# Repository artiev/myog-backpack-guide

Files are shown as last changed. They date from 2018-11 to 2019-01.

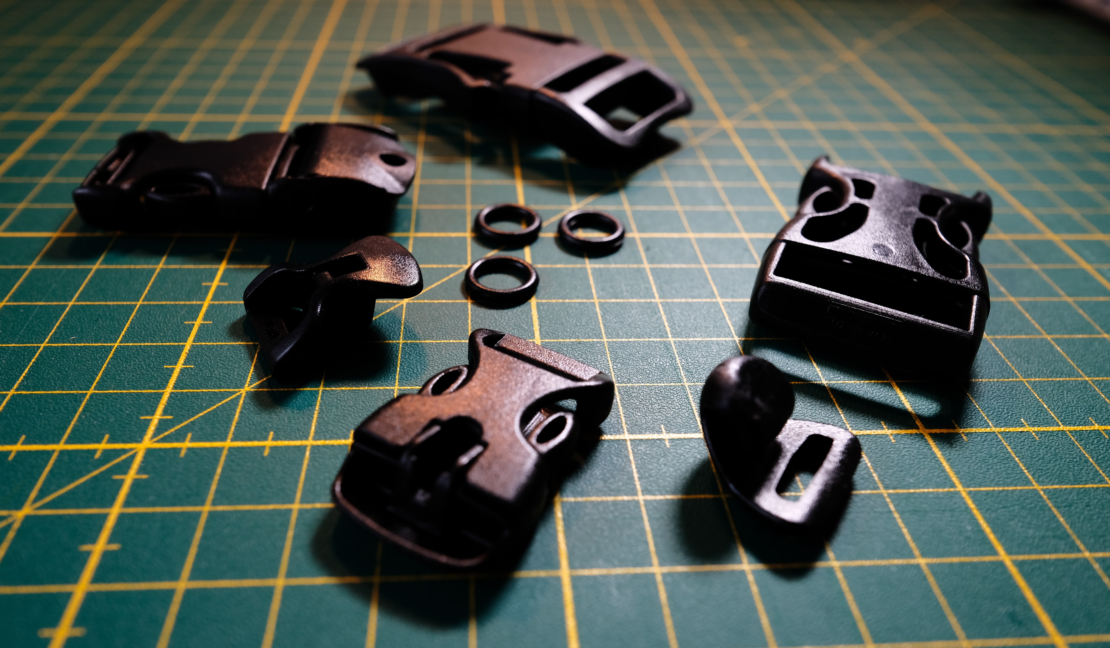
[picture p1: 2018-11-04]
media/images/highres/components-1.jpg

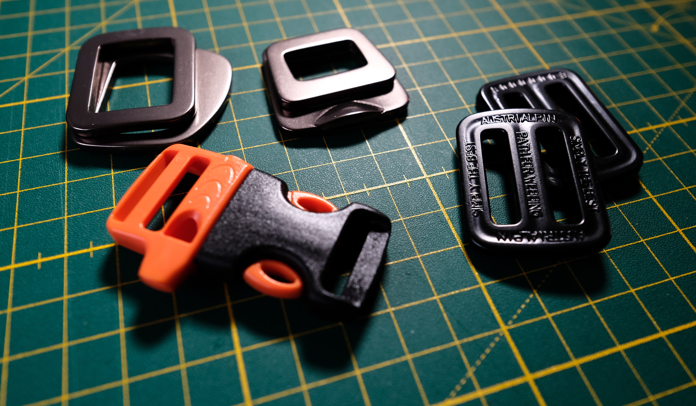
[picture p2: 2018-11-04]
media/images/highres/components-3.jpg

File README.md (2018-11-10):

A guide to building your own backpack
-------------------------------------

There is a growing trend in building outdoor gear: make it lighter.
And there is a will amongst trekkers and hikers alike to focus more on
the essentials than 'hoarding' half of your home on the trail.

This document here presented is a personal take on how I build my lightweight
backpacks. The following picture shows one of my self-made packs.

Example of custom back pack

In this essay, I will go through the complete process I follow to build packs,
and include a number of chapters covering (but not limited to):

- What features I consider when designing a pack.
- Choice of lighter fabrics and which materials I prefer.
- Different building methods and different designs I came up with.
- Complete documentation of a finished pack from design to execution.
- Where I find inspiration.
- How I work on these packs (workspace, tools, etc...)

If you are not familiar with any of this, then have a look
inside. If you are, and you are interested in looking at how I make my
backpacks from the research, sketches and designs to execution and example
photos, then read on!

Feel free to read, share, love, hate, but most of all, comment, review, raise
questions and concerns so I can make it better.

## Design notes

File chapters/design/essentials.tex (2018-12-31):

There is a backpack for any situation, and it's always interesting to look at what others are doing. I have a few backpacks - both commercial and custom made - at home I can analyse inside and out to figure out what I'm interested in. And there is a plethora of detailed pictures and designs on the web, ranging from home made MYOG articles, to high-end ultralight gear manufacturer, to cost-effective mass production design.

\subsection{Features}

When I try to define a set of features for a new backpack, the first step is to define the style and application of my design:

\begin{description}

  \item [Aesthetics] As basic as this sounds, I always enjoy a pack that doesn't look like I put it together in a few minutes. This will cost some extra fabric and or components in most cases, but I prefer it that way.

  \index{padding}
  \item [Load] The padding, weight balance and distribution, boiling down to the basic shape of a backpack is driven by how much weight it will need to carry. This impacts the construction of the shoulder straps, and the of the hip belt as well.

  \item [Weight] The basic weight of the backpack is tied to its construction, the materials used and its shape, the features I build in, etc... I rarely use this as a target, rather, I review everything else and try hard not to over-engineer a pack to limit the extra weight.

  \index{attachment}
  \item [Attachments] There is a ton of options to attach things to a backpack. In outdoor cases, I often have a tent and/or sleeping pad attached on the sides and bottom of the pack, I also use walking poles which I often strap on the side of the pack.

  \index{pocket}
  \item [Pockets] Whether inside or outside, pockets are an essential part of a pack. Depending on how you usually organise your pack, you would consider internal compartments, inside pockets, outside mesh pockets, and so on. I personally don't care much for pockets, as I organise my gear in stuff sacks. But I often need to attach/store things on the outside for easy access, or for drying.

  \index{roll-top}
  \index{velcro}
  \item [Closure] There is a ton of different way to close a backpack. To name but a few, I often consider roll tops, zippers, velcro, tie-ins or a mix of these.

  \index{padding}
  \item [Padding] Padding can be essential, or completely superfluous depending on what you carry, and how you carry it. I always build in a sleeve of some kind following the entire width and length of the pack to be able to add/remove foam padding depending on the trip.

  \index{hip-belt}
  \item [Hip-Belt] For me, and essential part of any hiking/trekking pack. The rare packs I built without a hip-belt, I gave away because I never use them. Now whether I want the hip-belt complete with padding, or just a simple strap depends on the weight I plan on carrying. But it's always a good weight investment.

\end{description}

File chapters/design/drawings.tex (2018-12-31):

When working on a pack, I make tons of sketches and drawings. I start with the basic shape, I add the features I have in mind, I draw multiple mock-ups and variants of that shape, together with its prominent features. Then, I slowly focus on the details, looking at every features, each getting variants of their own. And so on, until I get a pretty good idea of what I want to build.

\index{sketch}
\illustrate{media/images/design-drawings-1}
{Example of drawing process (page one)}
{img:design-drawings-1}

In the sketches from illustration \ref{img:design-drawings-1} and \ref{img:design-drawings-2}, you can see the concept I put together before even starting working on the pack from the picture \ref{img:pack-front-full-intro}. It might not seem like a lot, but it's because I've been sketching similarly built packs for a while, and I used previous sketches, packs and mock-ups as the base for this one. I also put together a collection of images of similar packs and detailed shots of features I was going for, which complement these sketches a lot.

\index{sketch}
\illustrate{media/images/design-drawings-2}
{Example of drawing process (page two)}
{img:design-drawings-2}

\index{feature}
\index{pocket}
\index{shock cord}
\index{compression strap}
\index{hip-belt}
\index{padding}
For me, it's important that I highlight the features I want to add beforehand. For this pack, I knew it would have no external pockets, and instead use a front interlaced elastic shock cord for drying stuff while walking or tucking away some piece of clothing quickly. I also wanted to add a series of straps on each side of the pack for attachment and compression which I could use to strap trekking poles or a water bottle holder. On top of that, I often add a set of attachment on the bottom of the pack which can hold a closed cell foam sleeping pad (important detail, as it tells me the dimensions). In the end, I want to use that pack for loads around 5-7 kg, so a hip belt will be a must, and I might need to have the possibility to add foam padding for my back depending on what I carry.

\illustrate{media/images/pack-front-full}
{The end result of the example design in illustration \ref{img:design-drawings-1}}
{img:pack-front-full-intro}

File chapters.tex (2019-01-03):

\chapter{Introduction} \label{chap:intro}
\input{chapters/introduction/index}

\chapter{My teeny tiny workspace} \label{chap:workspace}
\input{chapters/workspace/index}

\chapter{Find the inspiration} \label{chap:inspiration}
\input{chapters/inspiration/index}

\chapter{Drawing up a concept} \label{chap:drawing}
\input{chapters/design/index}

\chapter{Dimensions \& Measurements}\label{chap:dimensions}
\input{chapters/dimensions/index}

\chapter{Fabrics and Materials} \label{chap:materials}
\input{chapters/materials/index}

\chapter{Construction Techniques and Tips} \label{chap:techniques}
\input{chapters/techniques/index}

\chapter{The finished pack} \label{chap:pack}
\input{chapters/pack/index}

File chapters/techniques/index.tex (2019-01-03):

\section{Choose a sewing thread}\label{sec:sewing-thread}
\input{chapters/techniques/thread}

\section{Stitching for abuse}\label{sec:stitching-for-abuse}
\input{chapters/techniques/stitching}

\section{Backpack construction details}\label{sec:construction-details}
\input{chapters/techniques/construction}

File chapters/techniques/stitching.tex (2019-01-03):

I find it cumbersome to use a heavy-duty thread when sewing together a backpack. Parts of the pack which involve stitching together multiple layers of fabrics can sometime be quite tough on my sewing machine if the needle combined with the thread make for a wide diameter to punch through. So I use a thinner thread instead (see \ref{sec:sewing-thread}).

\index{triple stretch stitch}
\index{backstitch}
In combination with this, I use a special stitch, often referred to as the triple stretch stitch or backstitch, which is very robust yet flexible but still uses a single thread and a single needle. The result is much stronger than the tensile strength of the thread itself, and its construction has the added benefit of rendering a single point of failure almost impossible. As the triple pass (two times forward, one time backward each step) prevents any snapped thread from getting loose, resulting in a catastrophic failure of your seam.

The backstitch also allows a seam to stretch beyond what the thread's would normally offer, resulting in overall less stress on a single thread under heavy loads.

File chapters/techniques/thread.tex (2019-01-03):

When it comes to choosing your thread, there is of course no right or wrong choice. But there are a few things to consider, and then, there is experimentation, trial and error.

\index{thread}
For outdoor applications, and more specifically backpacks, you obviously want to consider the absolute tensile strength of your sewing thread so your seams can live through some abuse, but it is by far not the only criteria. Resistance to ultraviolet light, exposure to water (fresh water as well as sea water) and ability to stretch are amongst the important factors. Personally, I also consider how easy it will be to sew with a particular thread, which is mostly defined by the thread size and quality together with the choice of needle.

\begin{note}
  The choice of needle is not random either, I wanted easy-to-find, universal needles which can easily work through multiple layers of tightly woven and/or coated fabrics. Anything below 90/14 tends to break or bend a little too often for my taste. But I can buy a box of 90/14 or 100/16 all purpose needles anywhere.
\end{note}

Most of the common-man's threads will be either Nylon or Polyester, woven in various ways, advertising various qualities. One can also find higher quality - higher price - threads like PTFE, Dyneema, Kevlar and more but I think this would be beyond the point of building your own pack at home (and these would most likely outlast most fabrics you would use anyway).

\illustrate{media/images/place-holder}
{Illustration of multiple sewing threads}
{img:sewing-threads}

\index{triple stretch stitch}
If only for its resistance to UV exposure, Polyester is the way to go. It is very durable and also offers a very good tensile strength for relatively thin threads. As to the thread size, I always prefer triple stitching a thinner thread than having to deal with a cumbersome heavy thread and beefier needles. It allows a higher combined strength than a heavier single-stitched thread, and allows the fabric under load to stretch together with the tread without tearing the seams. The section \ref{sec:stitching-for-abuse} will provide more details on how I use such thin threads.

Unfortunately, as there is no universal unit - or any proper conversion system - for thread thickness, I can only give you a tensile strength recommendation and which needle size I use for this particular thread. I use a good quality German-made 100\% polyester thread from Alterfil (the S-100) with a tensile strength of 1570 cN (3.5 pounds of force) with 19\% elongation which is around half the single-stitch tensile strength recommended for a backpack seam ( approx. 3000 cN or 6.7 lbf). The S-100 is working perfectly with a size 90/14 or 100/16 universal needle on all fabrics I've tried.

\input{media/tables/alterfil-tensile-strength-recomendations}

Make sure you get yourself a high quality sewing thread, it will be worth every cent. Lower quality threads will probably be enough to hold the seams together (decent tensile strength) but sewing with them will soon become a nightmare. The main issue I have with lower quality products is the uneven weaving of the filaments that can leave bulges and notches along the thread. These imperfections will catch on anything they can on your sewing machine and fabrics, and the thread might tear for no reason. Plus, I find using high quality thread much more forgiving when used with a sewing machine on which the tension is not perfectly calibrated.

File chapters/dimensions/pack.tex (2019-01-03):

\begin{warning}
  The different panel's construction seams and extra fabric should be accounted for before cutting the panels. Refer to section \ref{sec:seams-and-cutouts} for more.
\end{warning}

As I just expressed my interest in balancing the shapes and dimensions of the bag through the golden ratio, I should start by saying this is not an exact science. I mostly use it to draw the basic shapes and arrange the different features together, and then, I often deviate a little. But all in all, it's a guideline.

\illustrate[.6]{media/sketches/pack-full-3d.pdf}
{Crude 3D sketch of backpack shape and size}
{ske:pack-full-3d}

\index{golden ratio}
In the illustration \ref{ske:pack-rough-cut}, the golden ratio is not obvious, but it is there. If we look at the front panel, the golden ratio is only supposed to impact the assembled pack, and therefore not visible in the fabric cut-outs ($\frac{750}{300} \gg 1.6$), but if you account for the $20cm$ planned for the roll-top and include some compression, you're getting pretty close ($\frac{550}{300} = 1.8$). I actually do prefer a slimmer backpack, but one could definitely get closer to the $1.6$ in any design.

\illustrate{media/sketches/pack-rough-cut.pdf}
{Rough backpack dimensions including seam allowance of 10mm}
{ske:pack-rough-cut}

I have tried many different combinations and ratios, and I find the best looks comes from ratios between $1.65 < \varphi_{front} < 1.85$. These also account to some extent to my torso length (as I am slim and tall).

\begin{note}
  \index{roll-top}
  The 20cm reserved to the roll-top is not for waterproofness or aesthetics, but about the extra volume this offers (approx 6 litres) if I need to carry more bulk.
\end{note}

\index{shoulder width}
With that in mind, my second constraint is given by the overall pack width I am aiming for, and that depends mostly on my shoulder width. There is a very simple reason for that: it's not actually about the shoulder width itself (that impacts more the straps design) but it is more about the freedom of movement of my arms. I do not want my backpack to to be wider than my rib cage, and for my arms and elbows to constantly hit and rub on the pack and create discomfort.

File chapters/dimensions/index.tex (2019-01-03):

\input{chapters/dimensions/introduction}

\section{The basic shape}
\input{chapters/dimensions/pack}

\section{The front panel: aesthetics \& usability}
\input{chapters/dimensions/panel-front}

\section{The side panels: compression}
\input{chapters/dimensions/panel-side}

\section{The back panel: comfort}
\input{chapters/dimensions/panel-back}

\section{The bottom panel: robustness}
\section{The shoulder straps: lightweight}
\section{The hip belt: padding}

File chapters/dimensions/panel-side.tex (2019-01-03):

When designing the side panels (both sides are using the same design), my main focus is to provide proper compression straps to help bring the load of the pack - especially its centre of gravity - as close to my back as possible. On top of that, I want to make sure the bulk of the pack and the heavy items can be placed and compressed at the bottom of the pack in order to carry most of the weight on my hips.

To solve this, I always design a side panel with 3 lines of compression, equally spaced out, and overall offset to the upper part of the backpack's main body. In this specific instance, I use 3 separate straps, but for ultralight purposes, you could use a single - static or shock - cord zigzagging through 6 tie-in points (including one adjustable anchor).

Once again, the golden ratio can help you out. If you take the middle strap as the reference, you can place it at $H / \varphi$ where $H$ is the closed pack height. Here, the pack should be roughly 550mm high when closed up, meaning the middle strap can be placed around $550 / 1.62 = 339mm$ from the bottom.

To make things simple based on the illustration \ref{ske:panel-side-design}, you can work your dimensions from:

\begin{equation}
  \left\{
    \begin{array}{rl}
     \varphi &\approx \dfrac{A+B}{B+C}\\
      H &= A+2 \times B+C + 3 \times w_{webbing}\\
    \end{array}
  \right.
\end{equation}

And we already know:

\begin{equation}
  \left\{
    \begin{array}{ll}
     \varphi = 1.62\\
      H = 550mm\\
      w_{webbing} = 15mm
    \end{array}
  \right.
\end{equation}

Now, I'll spare you the math, and just get to the point (I made some approximation to have nice round numbers):

\begin{equation}
  \left\{
    \begin{array}{rl}
      A &= 200mm\\
      B &= 110mm\\
      C &= 85mm
    \end{array}
  \right.
\end{equation}

\illustrate[.55]{media/sketches/panel-side-design.pdf}
{Concept of the side panels designed for pack compression}
{ske:panel-side-design}

Aside from shifting the pack's centre of gravity as low and close to the body as possible, leaving the bottom part of the panel "free" of compression straps also offers the possibility to add side pockets to your pack.

Since I rarely use them on multi-day hikes, I decided against them for this backpack, but for day packs these pockets can come very handy, and I build side pockets in all the time.

\begin{note}
   With this system, you could have a $170 \times 150mm$ side-pocket on each side and use the lowest compression strap as a tightener for, for example, securing a water bottle.
\end{note}

One thing to consider is whether you want the straps to have a quick-release mechanism or if you prefer simple constructions like a ladder-lock. This can have an impact on the usefulness of your straps beyond compression. I always design at least one compression strap with a quick-release buckle, or some equivalent system, so I can effortlessly secure anything to the side of the pack, from a tent, to trekking poles, to a rain jacket. More details on construction options and techniques can be found in section \ref{sec:construction-side-pockets}.

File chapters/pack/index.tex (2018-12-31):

\section{The complete pack}

\index{daisy chain}
\index{shock cord}
\illustrate{media/images/pack-front-full}
{Front construction of the pack with daisy chains and shock cord}
{img:pack-front-full}

\illustrate[.75]{media/images/pack-side-poles}
{Side of the pack with example holding trekking poles}
{img:pack-side-poles}

\index{sleeping pad}
\index{attachment}
\illustrate{media/images/pack-front-pad-poles}
{Pack with nominal load and sleeping pad attached}
{img:pack-front-pad-poles}

\section{Details of construction}

\subsection{Gear straps and their purpose}

\illustrate[.75]{media/images/pack-side-full}
{Overview of the side construction of the pack}
{img:pack-side-full}

\index{roll-top}
\illustrate{media/images/pack-strap-roll-top}
{Details of the roll-top straps (same construction on both sides of the pack)}
{img:pack-strap-roll-top}

\index{daisy chain}
\illustrate{media/images/pack-front-detail-strap}
{Details of the pack's front daisy chain (bottom loop)}
{img:pack-front-detail-strap}

\index{compression}
\illustrate{media/images/pack-strap-compression}
{Construction of the compression straps (3 per side, all with same construction for right handed attaching)}
{img:pack-strap-compression}

\subsection{Shoulder straps and sternum strap}

\subsection{Hip Belt}

\index{hip belt}
\illustrate{media/images/pack-hip-belt-1}
{Details of the hip belt construction}
{img:pack-hip-belt-1}

\index{hip belt}
\illustrate{media/images/pack-hip-belt-2}
{Details of the hip belt unconventional closure}
{img:pack-hip-belt-2}

\subsection{Volume Extension Strap (extra)}

\index{compression}
\illustrate{media/images/pack-extra-volume-strap-1}
{Details of the additional strap to extend pack volume safely (front)}
{img:pack-extra-volume-strap-1}

\illustrate{media/images/pack-extra-volume-strap-2}
{Details of the additional strap to extend pack volume safely (back)}
{img:pack-extra-volume-strap-2}

\illustrate{media/images/pack-extra-volume-strap-3}
{Details of the additional strap to extend pack volume safely (back, detached)}
{img:pack-extra-volume-strap-3}

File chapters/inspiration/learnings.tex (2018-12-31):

\subsection{Database} \label{sec:gear-database}

\illustrate{media/images/gear-database}
{Extract of the gear database}
{img:gear-database}

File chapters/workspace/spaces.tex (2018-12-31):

For those who know me, the least one can say is that I like order. And trust me, a workshop can get messy ! I usually fold fabrics, and sort components, in a well organised system, stored away in different boxes when I’m not sewing anything. That way, I can fetch exactly what I need (or I think I need) when I need it. I simply have a much better space to just let the ideas flow when my table is not drowning under cuts of different material, with sewing thread everywhere, components lying around on the table and on the floor... Well, you get the picture.

Most of the time I spend at my workspace is divided in three phases.

\begin{itemize}

  \item Research and drawing
  \item Quick prototyping and trying things out
  \item Putting together a complete pack

\end{itemize}

For each of this phases, I re-arrange my workspace a little bit different. They are, at the end of the day, the same place, but maybe I can give you a few pointers as to where to start. The rest will be up to you.

\illustrate{media/images/workspace-1}
{My workspace when I cleaned it up}
{img:workspace-1}

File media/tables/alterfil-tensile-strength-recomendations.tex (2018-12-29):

\begin{table}[H]
  \centering
  \begin{tabular}{ | l | l | p{8cm} | }
    \hline
      \textbf{Thread} &
      \textbf{Tensile Strength} &
      \textbf{Recommended use} \\
    \hline
      S-120 &
      1230 cN / 2.76 lbf &
      sports jackets, waistcoats, trousers, coats, jackets, shirts, dresses, sportswear, fabrics of micro-fibre, blouses, underwear/linen, home textiles, curtains, ... \\
    \hline
      S-100 &
      1570 cN / 3.52 lbf &
      outer-wear, sport jackets, waistcoats, trousers, coats, fabrics of micro-fibre, quilting machines \\
    \hline
      S-80 &
      2100 cN / 4.72 lbf &
      jeanswear, sportswear, quilted ornaments, working clothes \\
    \hline
      S-50 &
      3200 cN / 7.19 lbf &
      jeanswear, sportswear, quilted ornaments, working clothes, leather, \textit{rucksacks}, sleeping bags, mattresses, upholstery, hand- and travelling bags \\
    \hline
      S-35 &
      4000 cN / 8.99 lbf &
      jeanswear, quilted ornaments, sportswear, upholstery, \textit{rucksacks} \\
    \hline
  \end{tabular}
  \caption{Alterfil's polyester sewing thread tensile strength recommended use}
\end{table}

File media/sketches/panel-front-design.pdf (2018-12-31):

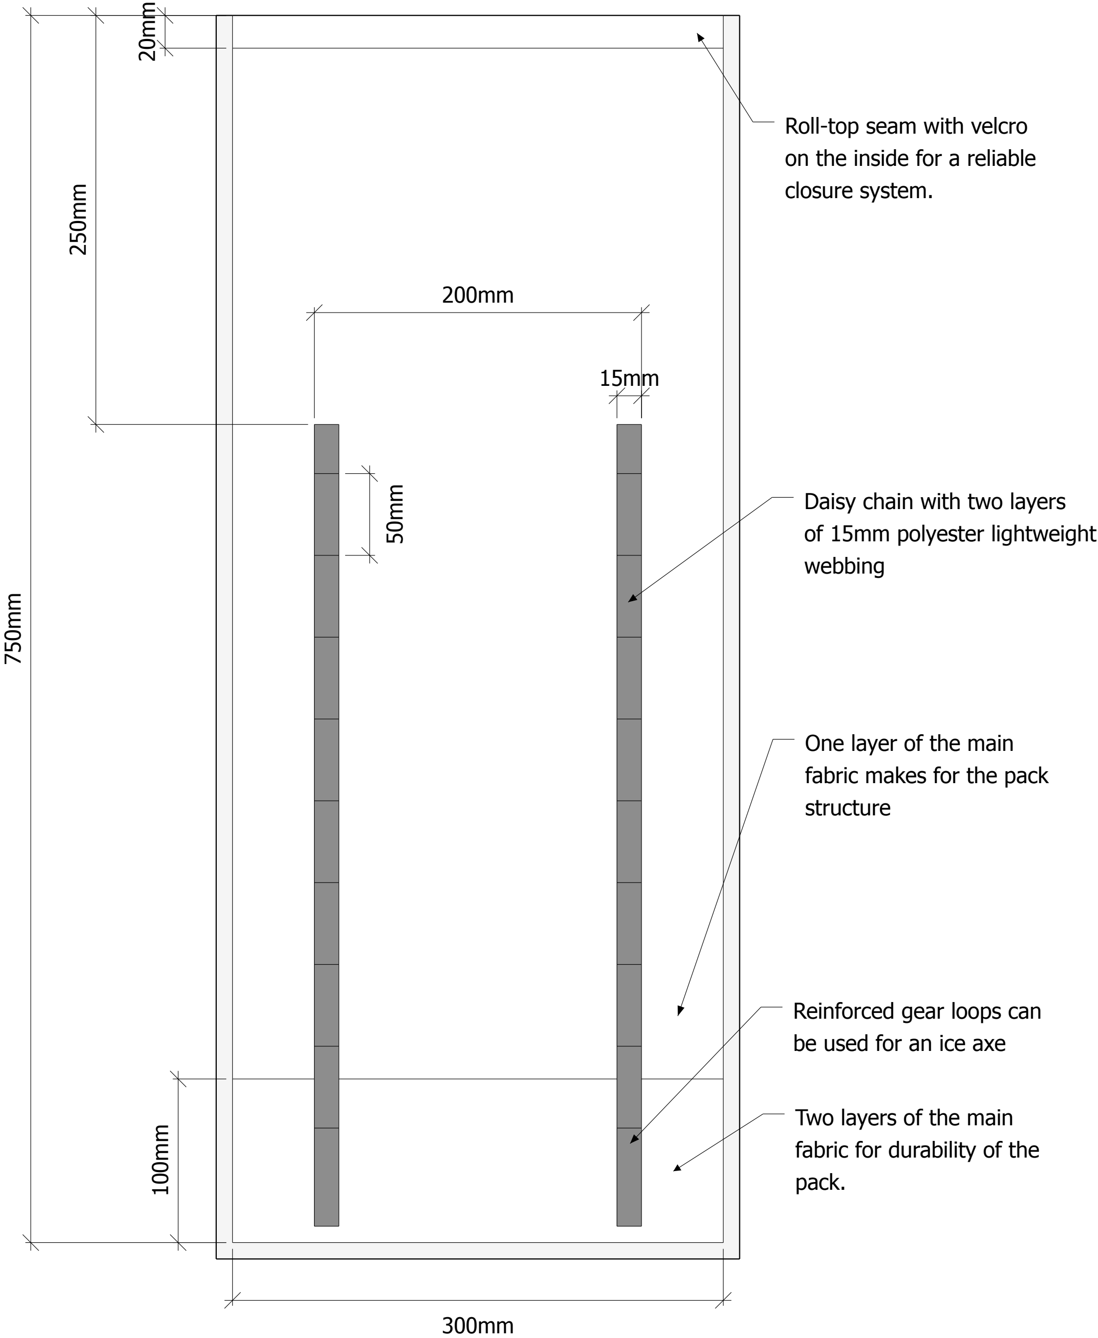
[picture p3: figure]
Two layers of the main fabric for durability of the pack.; Daisy chain with two layers of 15mm polyester lightweight webbing; One layer of the main fabric makes for the pack structure; Roll-top seam with velcro on the inside for a reliable closure system.; Reinforced gear loops can be used for an ice axe

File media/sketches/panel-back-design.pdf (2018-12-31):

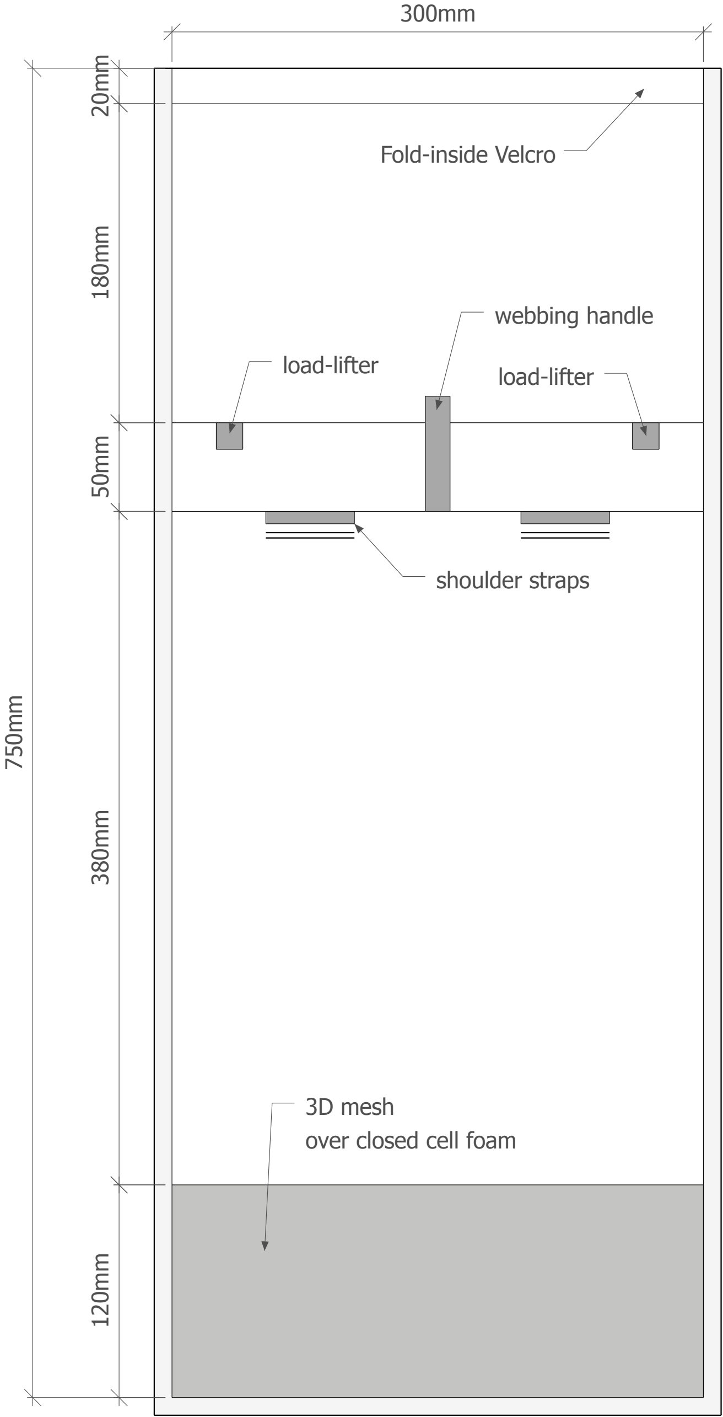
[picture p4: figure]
load-lifter; webbing handle; shoulder straps; 3D mesh over closed cell foam; Fold-inside Velcro

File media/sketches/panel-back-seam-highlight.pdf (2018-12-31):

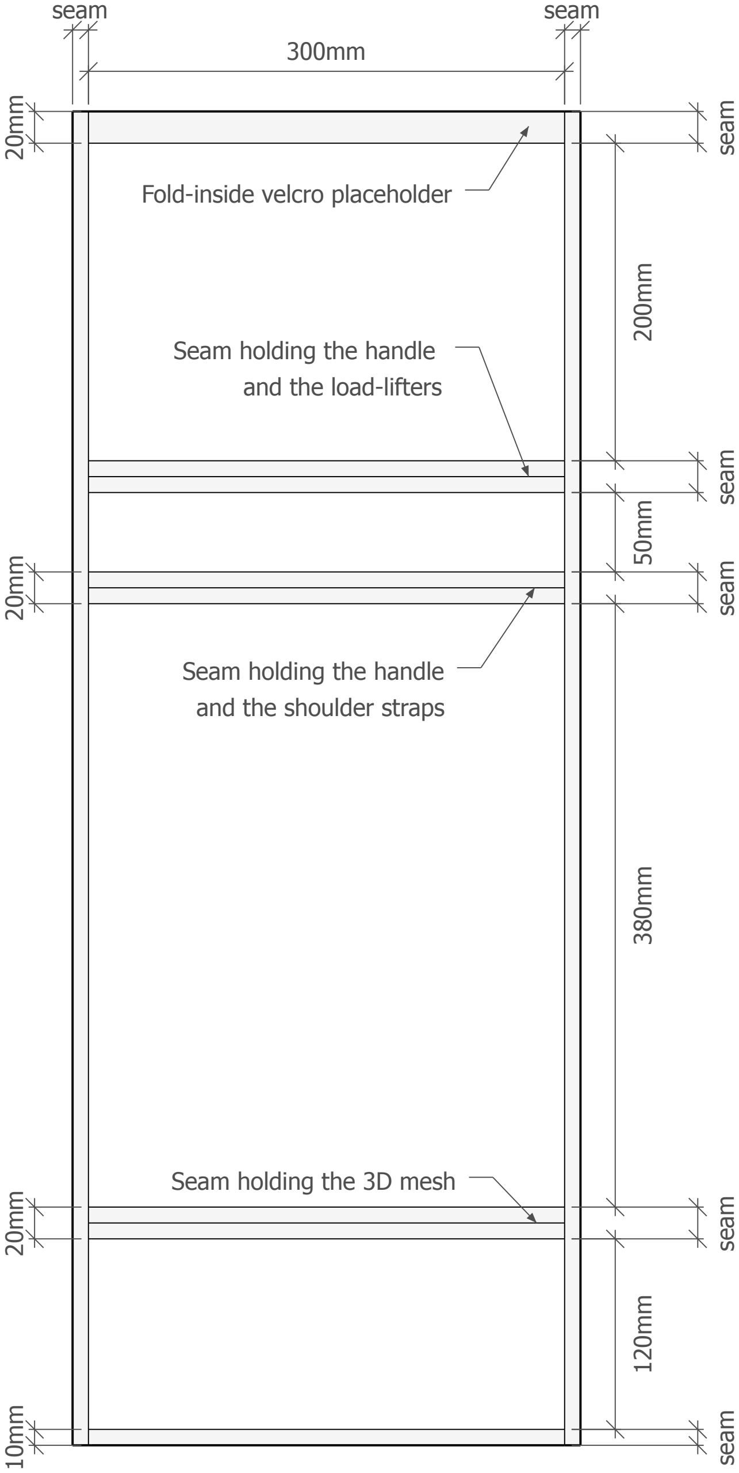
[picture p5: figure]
seam seam; seam; Seam holding the handle and the load-lifters; Seam holding the handle and the shoulder straps; Seam holding the 3D mesh; Fold-inside velcro placeholder

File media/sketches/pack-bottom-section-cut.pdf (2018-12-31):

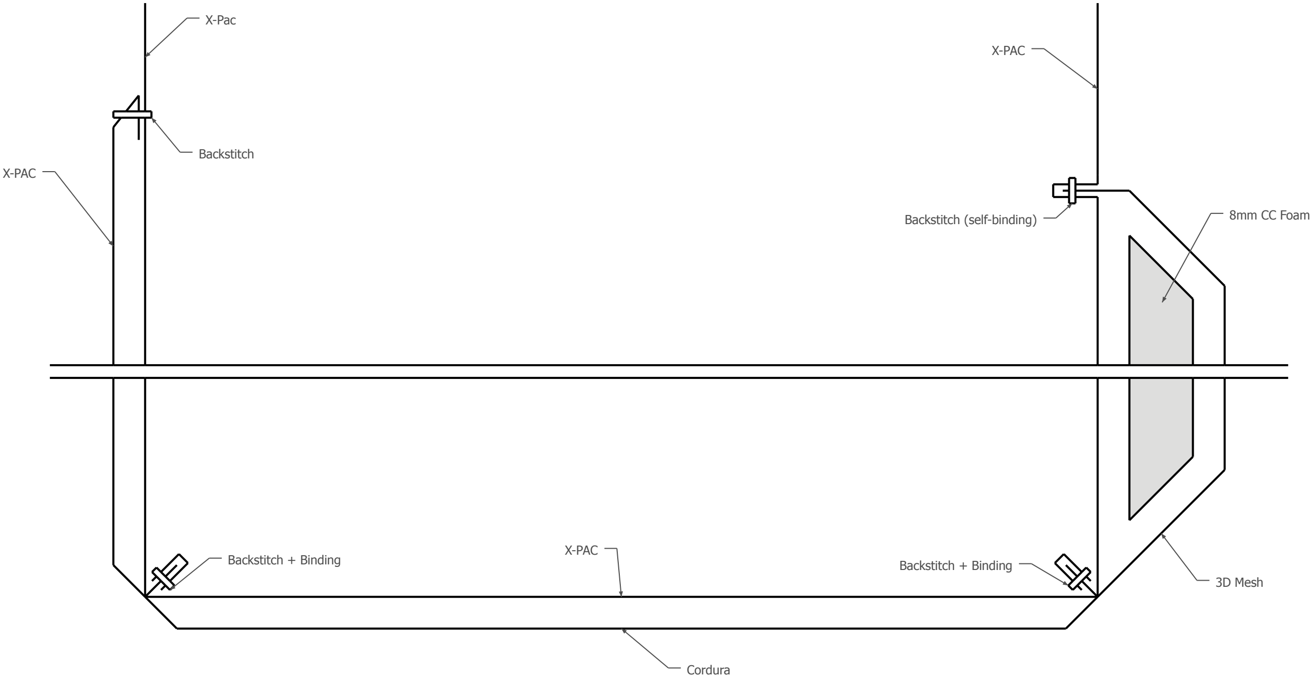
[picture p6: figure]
X-Pac; X-PAC; Backstitch; Backstitch + Binding; 8mm CC Foam; 3D Mesh; Cordura; Backstitch (self-binding)

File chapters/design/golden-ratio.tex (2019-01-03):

When I design a backpack, one of the major issue I face is getting the dimensions right, and how features are placed in relation to one another. From choosing the dimensions of the pack itself to settling on where compression straps are placed on the side panels or making up my mind on the size and placement of some mesh pockets, making an informed choice can be quite cumbersome.

Now, there is really only two criteria to consider: usability and eye-candy. Let's face it, when I spend 30 hours building a pack - which I do more often than not - I want the end result to be functional, but also pleasing enough so I can wear it proudly in public.

\begin{quote}
  When in doubt: golden ratio!
\end{quote}

Across the ages, when working out forms and dimensions in relations to each other, the golden ratio has played a major part of many concepts, from the roman architecture and the renaissance painting to many natural shapes and forms.

You can find a quick mathematical explanation below of how this number came to life, but for reference, the golden ratio is defined as follow.

\begin{equation}
  \varphi \approx 1.62
\end{equation}

The many applications of $\varphi$ revolve around the aesthetics of geometrical forms. A concrete list of example applications could be:

\begin{itemize}
  \item Define the basic rectangular shape of the backpack
  \item How high should a side pocket go
  \item Where to put compression straps
  \item How short a zipper closure can be
  \item Where to place load lifters
  \item How to offset a chest strap's or hip belt's quick release buckle
\end{itemize}

Now, I don't always rely on this ratio when working on a design, but it's a general guideline for these times where functionality and prior experience did not provide me with an answer. Have a look at the chapter \ref{chap:dimensions} to see some more concrete examples of where I use this ratio.

\begin{note}
  \index{divine proportion}
  The golden ratio (also known as the divine proportion) is an irrational number with deep mathematical roots (see Fibonacci sequence for more). In its most simple use, it can offer a eye-pleasing ratio between the length $a$ and the width $b$ of a rectangle ($a > b > 0$).

  \begin{equation}
    \centering
    \frac{a + b}{a} = \frac{a}{b}=\varphi
  \end{equation}

  And through clever manipulation and substitution, you achieve an exact formulae:

  \begin{equation}
    \centering
    \label{eq:golden-ratio}
    \varphi^2 - \varphi - 1 = 0
  \end{equation}

  The golden ratio $\varphi$ should solve the equation \ref{eq:golden-ratio}, and its only positive value is as follow:

  \begin{equation}
    \centering
    \varphi = \frac{1 + \sqrt{5}}{2} = 1.6180339\dots
  \end{equation}
\end{note}

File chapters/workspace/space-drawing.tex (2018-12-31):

I find most of my inspiration on the web. There are people out there who have better ideas than mine, and I don’t shy away from blatantly experimenting, learning and copying any concept or design I like. I am dedicating the entire chapter \ref{chap:inspiration} to how and where I find inspiration, so let’s just boil it down to the essentials here and look at the image \ref{img:workspace-2}.

\illustrate{media/images/workspace-2}
{My desk for researching and drawing new packs}
{img:workspace-2}

\begin{description}

  \item[Paper] I prefer a plain white fine grain A3 Canson sketchbook (I just love the space and the grain, and the lack of constrains of plain paper) but any paper/sketchbook would do of course. I stay away from millimetre paper because I don’t need accurate drawings.

  \item [Ball Pen] Just trust me, and don’t use a pencil and an eraser. It’s way better to draw, make mistakes, and draw again and again. Keep your complete history of designs. Take notes on them regarding why you would have erased it, what you think works and doesn’t.

  \item [Cutting Mat] A cutting mat is awesome to keep around as it gives a scale to anything you find online.

  \item [Measuring Tape] A tailor’s tape measure, so I can grab any of my packs and take a fresh set of measures to scribble it into a drawing. Any ruler would do, but working with fabrics and a rigid ruler is not ideal.

  \item [References] I keep some kind of inventory of the components I’ve tried and liked. I have tried loads of different webbing types and sizes, different buckles, different clips. Keeping track of whether they work together or not is essential. This is great to already get an idea of how I can put something together. See section \ref{sec:gear-database} for more details.

\end{description}

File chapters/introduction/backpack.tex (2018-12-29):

First things first, when reading the following chapter, keep one thing in mind: I do my best to design lightweight backpacks, but I wouldn't push it so far as to calling them ultralight packs. There are highly specialised, very talented backpack makers out there who focus all their attention on ultralight hikers (and thru-hikers),  and they come up with amazing featherweight designs. Personally, I have a less drastic approach to weight loss in general, but I am still aiming at a substantial weight reduction without hampering the functionality of my packs.

\subsection{The things one carries, and why it matters}

When you want to have a look at pack weight, you should first consider what exactly you are carrying. For a trip, the weight of my pack is divided in two categories:

\begin{itemize}

	\index{base weight}
	\item My \textbf{base weight} is the weight of my gear, this account for my sleeping system, my clothing, my shelter, and - of course - the pack I carry everything in.

	\index{consumables}
	\item Things like food, water, or the fuel for your stove, are weights which not only vary during a trip, but most importantly will differ from one trip to another. They are the \textbf{consumable} part of the weight you carry.

\end{itemize}

This separation in two categories finds its roots in a very simple truth: although you can be smart about what \textit{consumables} you carry, there is only so much weight you can avoid carrying for your hydration and caloric needs (water can't be altered to weight less, and calories don't come from thin air). Base weight, on the other hand, can be tremendously altered by your choices of items, and how they function together as an ensemble.

If you are reading this, then you probably have done some research already on how to hike lighter, and by now you should be familiar with the big three things which everyone should pay attention to:

\begin{itemize}

	\item Sleeping system
	\item Shelter
	\item Backpack

\end{itemize}

They represent the most part of your base weight, and also are historically the most overlooked piece of equipment when it comes to shaving weight.

\subsection{Example of weight distribution}

If you want to design a backpack, you will need to understand how your gear consumes weight. It is crucial you understand the fine balance between weight and comfort. Every one is different, and will want different levels of comfort, but more so, every trip is different, and will require different pack construction. A simple example can be drawn from a commercial, highly comfortable trekking backpack, which is my go to for loads of 8-10kg, and a frameless, padless backpack I user for loads around 5kg.

This is taken from one of my trips and the following pie chart shows how weight distribution was with conventional gear. I put together this kit to wander the Annapurna Circuit Trek with a focus on \textit{warmth} and \textit{comfort} at high altitude. I had a lot of constrains with the weather as I was hiking for 3 weeks straight, with no expectation for being able to resupply anything other than consumables. In this part of the Himalayas, the altitude variations between 800m and 5400m means temperatures between +25\degree C to -30\degree C.

\input{media/graphics/base-weight-pie-anapurna}

As you can see in this example, the weight of my backpack at the time was competing with my -30\degree celsius down sleeping bag. And I can tell you, both the sleeping bag and the pack where too heavy for what I needed. Despite the fact that my pack was already touching the decently light category at 1.1kg for a very comfortable pack.

An example of shaving a lot of base weight happened in one of my last trip: a fast-paced hike of Scotland's Great Glen Way where I walked 130km in 4 days. For this trip, I had to carry a complete shelter and sleeping system, but not a lot of anything else. So I switched to a custom made ultralight backpack (around 350 grams) and some ultralight 1-person tent (630 grams) with a closed-cell foam sleeping pad (400g). I also used a down quilt instead of a sleeping bag (10\degree C comfort, 395 grams) which was definitely too light.

In should become obvious weight if often a tradeoff with comfort. In that regard, every being different, you will have to find your "sweet spot" on your own.

\input{media/tables/baseweight-comparison-annapurna-scotland}

\subsection{Weight categories \& purpose}

The purpose of a pack is obviously to carry things. But the way I will use it make a huge difference in the way I design a pack. For example, I care little for inside pockets, I always carry some stuff outside my pack, I usually lug around loads between 3 to 8 kilograms (depending on how long I'm hiking for, and in which conditions) but most of my gear compresses well, so 40 litres is usually good enough.
For loads equivalent to 40 litres weighing 7 to 9kilograms, most commercially available backpacks oscillate between 1.20 and 1.80 kilograms, and specialised ultralight backpacks can go down to 300 grams.

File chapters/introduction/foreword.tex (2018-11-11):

There is something about making my own outdoor gear that I can't get enough of. I have always been a maker to some extent, and - usually - my creations are very short lived. I've come to think of it as being more about the process, about the work I put into making something, and the learnings I get from it, rather than about the outcome itself.

When it comes to outdoor gear, it is still about the process - obviously - but the outcome itself is tangible to a much greater extent than anything else I worked on until then. I can use it, abuse it, and improve upon every iteration. Take the example of backpacks: I can carefully plan every part of it, dedicate every feature to a particular problem I want to solve in a particular situation, and do tons of research. But when I am done, I end up with something more than the sum of my work, something I'm going to enjoy (or hate) for miles to come, literally. In my opinion, this is priceless.

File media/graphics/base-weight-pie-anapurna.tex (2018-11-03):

\def\angle{0}
\def\radius{3}

% Quick pack breakdown Annapurna 2017
% pack      1185   13,72
% photo	    1400   16,21
% sleeping  1530   17,72
% clothing  3230   37,41
% safety    1040   12,05
% walking   249    2,88
% total     8634   100,00

\begin{figure}[H]
\centering

\begin{tikzpicture}
  \foreach \percent/\name/\color in {
      2.88/Trekking Poles/black,
      16.21/Photography Gear/magenta,
      13.72/Backpack/red,
      17.72/Sleeping Bag/blue,
      12.05/Equipment \& Safety/cyan,
      37.41/Clothing/green,
    } {
      \ifx\percent\empty\else % If \percent is empty, do nothing
        \draw[fill={\color!50},draw={\color}] (0,0) -- (\angle:\radius)
          arc (\angle:\angle+\percent*3.6:\radius) -- cycle;
        \node at (\angle+0.5*\percent*3.6:0.7*\radius) {\percent\,\%};
        \node[pin=\angle+0.5*\percent*3.6:\name]
          at (\angle+0.5*\percent*3.6:\radius) {};
        \pgfmathparse{\angle+\percent*3.6}
        \xdef\angle{\pgfmathresult}
      \fi
    };
\end{tikzpicture}

\caption[Example of conventional base weight distribution]{Example of conventional base weight distribution for a 3 weeks backpacking trip with freezing temperatures, but no need for shelter}

\end{figure}

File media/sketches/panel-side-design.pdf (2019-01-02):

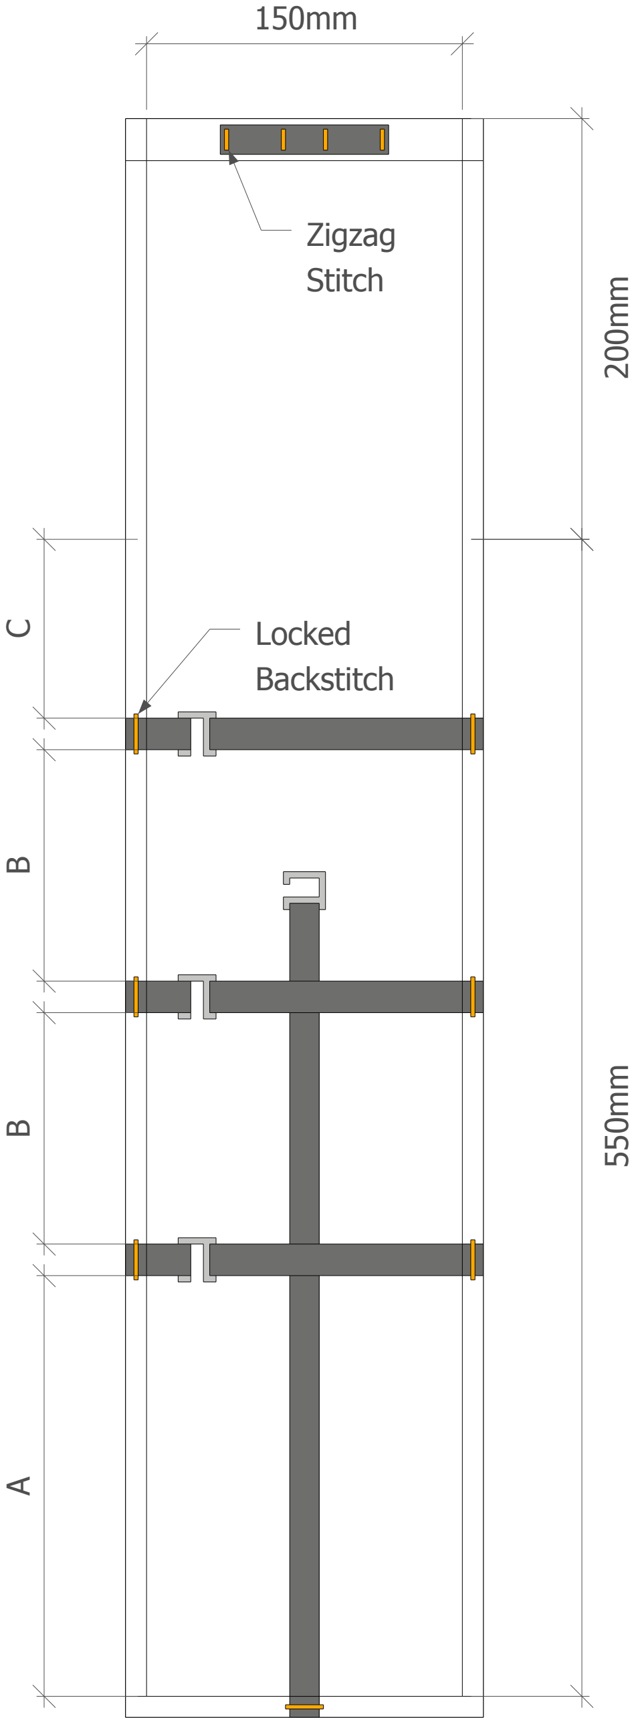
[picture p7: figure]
Zigzag Stitch; Locked Backstitch

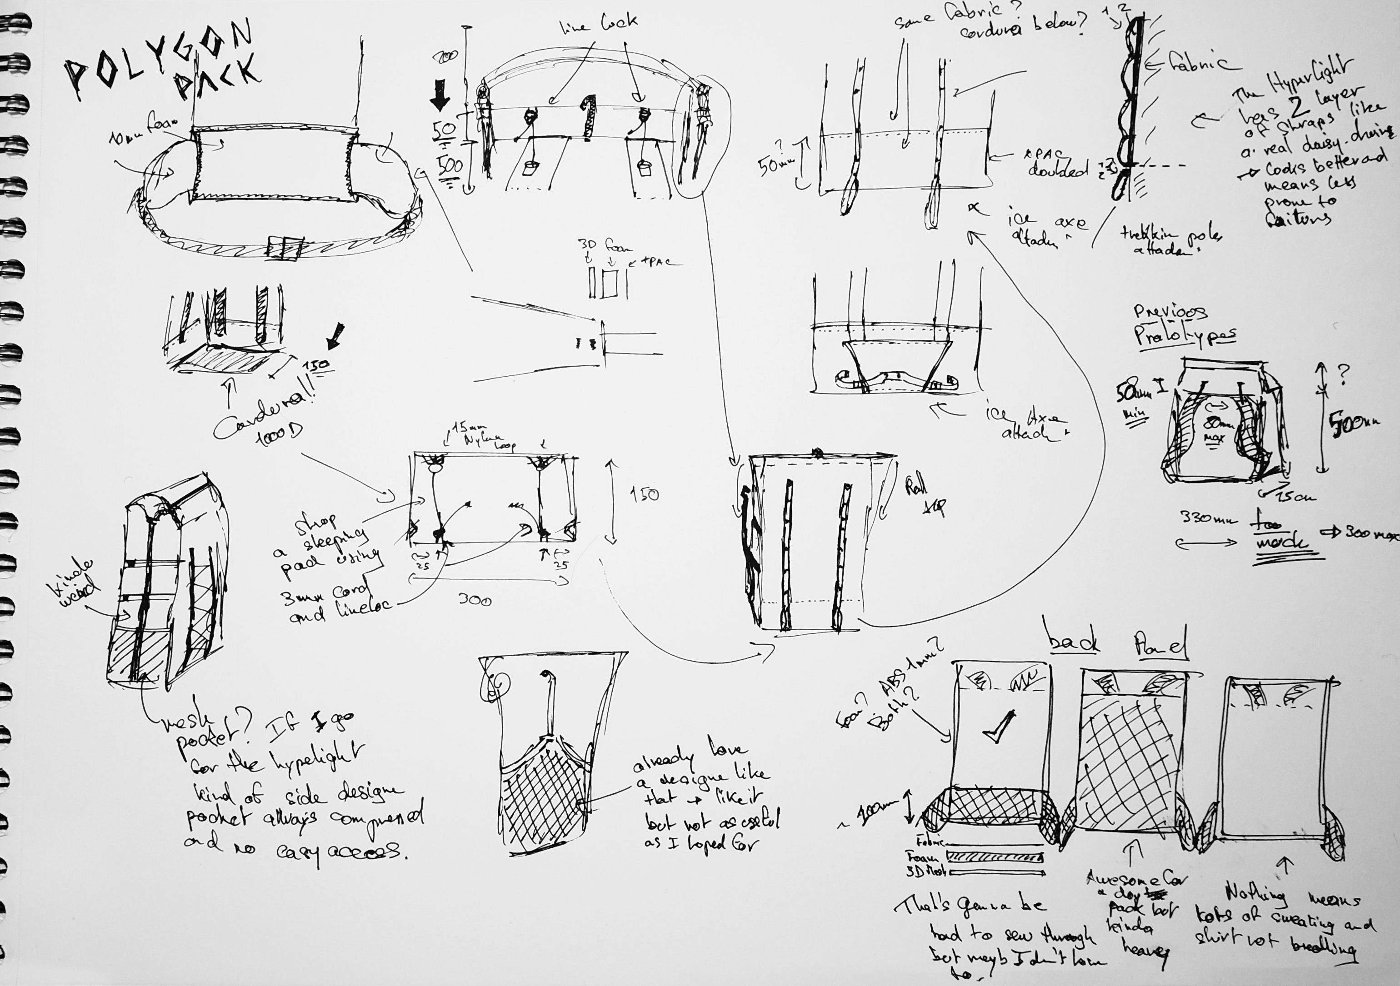
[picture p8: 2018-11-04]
media/images/highres/design-drawings-2.jpg

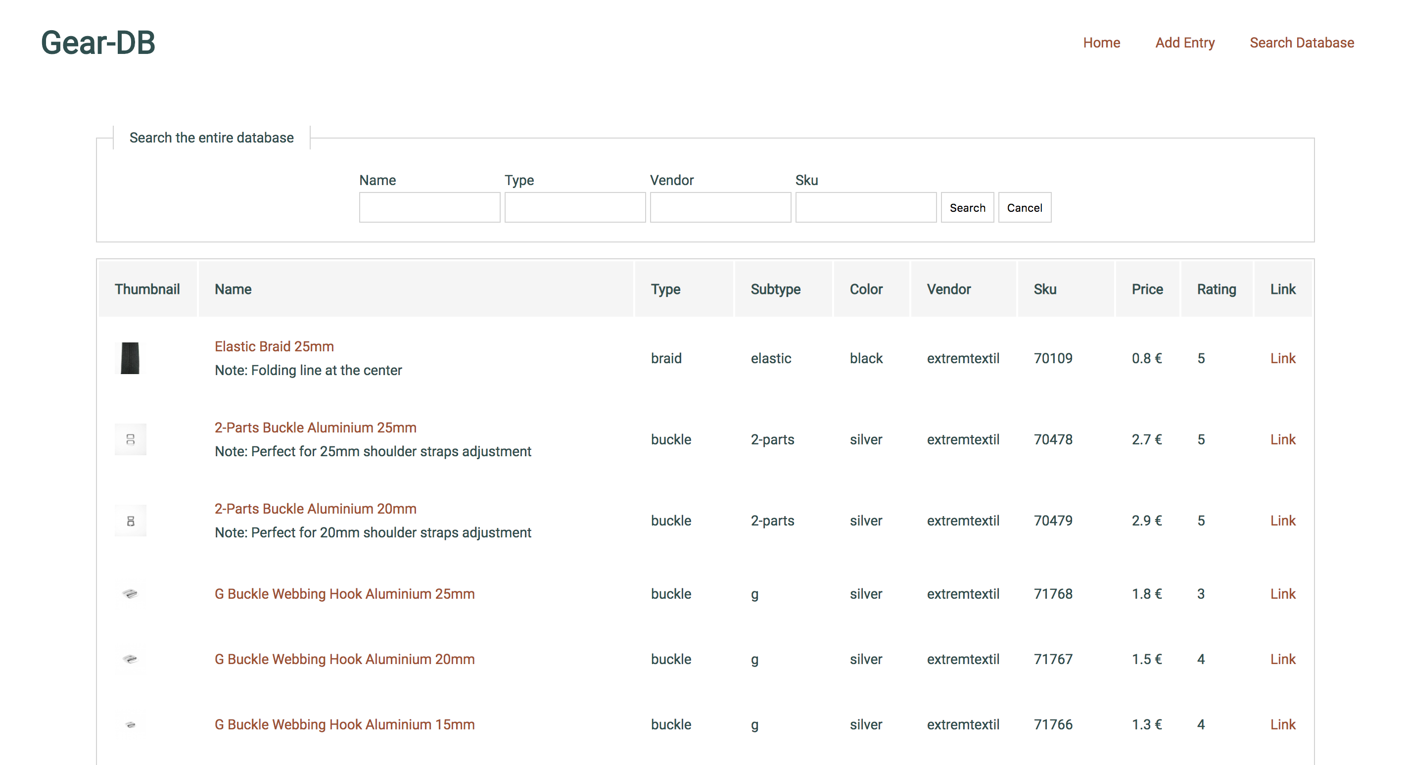
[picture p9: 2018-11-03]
media/images/gear-database.png

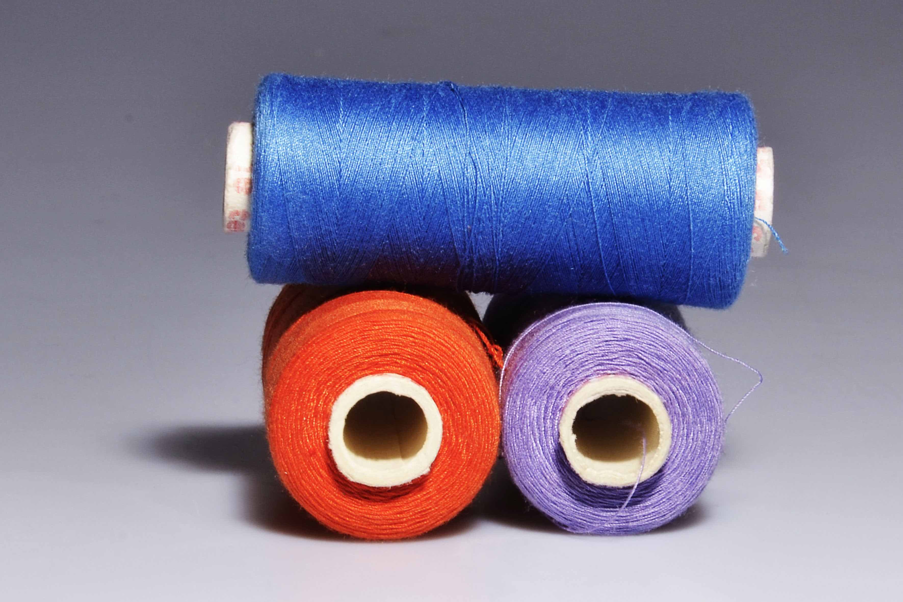
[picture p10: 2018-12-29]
media/images/place-holder.jpg

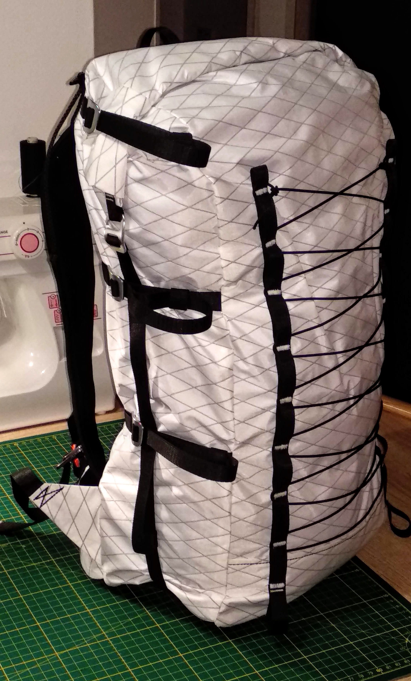
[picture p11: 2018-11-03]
media/images/pack-side-full.jpg

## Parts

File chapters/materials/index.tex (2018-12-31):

\section{What to look for in a fabric}
\input{chapters/materials/fabrics}

\subsection{Order samples first}
\input{chapters/materials/samples}

\section{My choice for fabrics}

\subsection{Heavy Duty Cordura}
\input{chapters/materials/cordura}

\subsection{Lightweight Ripstop Synthetic Fibres}
\input{chapters/materials/synthetic}

\subsection{Padding with 3D Mesh}
\input{chapters/materials/3d-mesh}

\subsection{Padding with closed-cell foam}

\subsection{Multipurpose Mesh}
\input{chapters/materials/mesh}

\section{Tried and True Components}
\input{chapters/materials/components}

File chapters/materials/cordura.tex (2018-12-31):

\index{cordura}
Cordura is a fantastic fabrics to work with, especially coated. Uncoated, it's a rather soft fabric (depending on the denier it comes in) and frays very easily. One thing you should consider is that coated Cordura is much stiffer than uncoated, resulting in you probably needing a lower denier then uncoated. Denier is the rating of the thread of fibre used to weave the fabric, the higher the denier, the heavier and more durable the fabric.

\index{nylon}
As it is mostly comprised of nylon fibres (normally solely, but it sometimes comes with a cotton blend), it does not soak up water or moisture much, meaning its weight when wet is not significantly higher than when dry.

Cordura is a great fabric for parts of a backpack which will have to endure more abrasion and stress than the rest. This is usually true of the bottom part of a pack, when it is standing on the ground, and when items inside apply pressure at certain points.

\index{cordura}
\illustrate{media/images/fabrics-cordura-set-1}
{Cordura sample set}
{img:fabrics-cordura-set-1}

\index{cordura}
\illustrate[.75]{media/images/fabrics-cordura-set-2}
{Close-up of different denier Cordura weaves}
{img:fabrics-cordura-set-2}

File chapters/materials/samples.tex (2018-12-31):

\index{sample sets}
Any self-respecting fabrics retailer will offer sample sets. Use them! I cannot stress that enough! There is no amount of research in the world that will give you a feel for a fabric. But a few bucks spent on acquiring a complete set of samples for what you need will. Have a look at the illustration \ref{img:fabrics-sample-sets} to know what I mean by that.

\illustrate{media/images/fabrics-sample-sets}
{My beloved sample box}
{img:fabrics-sample-sets}

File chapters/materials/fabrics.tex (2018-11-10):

I have spent quite a few bucks on different kinds of fabrics. There has been a few which really stood out from the rest by how strong they feel, or how easy they are to work with. There is a few things I'm looking for in the fabrics I use apart from the aesthetics:

\begin{description}

  \index{ripstop}
  \item [Ripstop] A backpack will get punctured, scratched, tossed around, overloaded and so on. If there is one thing I expect from the fabric, is that it survives for the duration of my trip no matter what tear and wear the pack goes through. Ripstop treatment is the process of interweaving a stronger filament at short intervals within the fabric, with a recurring pattern - say 5 mm by 5 mm squares - so that a tear in the fabric will be stopped by the stronger thread. It also helps the sewing process by offering anchors, and makes a fabric overall much more durable.

  \index{coating}
  \index{waterproof}
  \item [Water resistant coating] There is one thing that does not work well for traveling light, and it's having a fabric that absorbs water, making the pack much heavier than it should be. There is plenty of methods for coating a fabric, and there is enough demand for waterproof fabrics that the price of coated versus uncoated is close enough not to even care.

  \index{humidity}
  \item [Soaking resistance] Different fabrics come with different blends of material. Some of these materials' fibres resist much better to water than others. When I am considering a fabric, the water resistant coating is one thing, but it's ability to not get heavier with rain or humidity is almost as important. As the fabric does not weight more, and does not need drying.

\end{description}

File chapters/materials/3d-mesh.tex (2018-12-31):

\index{mesh (3D)}
\illustrate{media/images/fabrics-3d-mesh-set}
{Example of 3D mesh}
{img:fabrics-3d-mesh-set}

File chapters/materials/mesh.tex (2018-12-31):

\index{mesh}
\illustrate{media/images/fabrics-mesh-set}
{Example of Multipurpose Mesh and Netting}
{img:fabrics-mesh-set}

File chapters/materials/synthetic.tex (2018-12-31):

\index{coating}
\illustrate{media/images/fabrics-coated-set}
{Example of coated fabrics}
{img:fabrics-coated-set}

\index{nylon}
\illustrate{media/images/fabrics-tent-set}
{Example of lightweight tent fabrics (mostly Nylon)}
{img:fabrics-tent-set}

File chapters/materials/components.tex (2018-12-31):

\illustrate{media/images/components-1}
{Commonly used components}
{img:components-1}

\illustrate{media/images/components-2}
{Commonly used components}
{img:components-2}

\illustrate{media/images/components-3}
{Commonly used components}
{img:components-3}

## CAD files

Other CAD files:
media/sketches/raw/pack-bottom-section-cut.skp
media/sketches/raw/pack-full-3d.skp
media/sketches/raw/pack-rough-cut.skp
media/sketches/raw/panel-back-design.skp
media/sketches/raw/panel-back-seam-highlight.skp
media/sketches/raw/panel-front-design.skp
media/sketches/raw/panel-side-design.skp
media/sketches/raw/panel-side-multiple-designs.skp

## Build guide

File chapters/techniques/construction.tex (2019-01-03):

\subsection{Account for the seams before you cut}\label{sec:seams-and-cutouts}

In most of the drawings in this documentI only highlight the basic dimensions of the finished panels and add a symbolic outer seam allowance.

Before cutting any panels for a backpack, you should pay attention to all the seams and extra fabric necessary to bind and build all the features of each panel.

The illustration \ref{ske:panel-back-seam-highlight} is an example of how seams can impact fabric cut-out of the panel shown in illustration \ref{ske:panel-back-design}, and why you should always have a few drawing of the features of your pack. In this instance, I would cut 4 separate panels and assemble them into a complete back panel before starting working on another panel.

\begin{note}
  When working on design which involve multiple parts per panel, you also want to consider the fabric's patterns, and make sure they match!
\end{note}

\index{seam allowance}
Seam allowance is crucial to the construction of a backpack. After experimenting a lot, I realised I tend to sew seams 10mm to 15mm from the side of the fabric. With that in mind, if I leave more than 15mm of fabric for the seem allowance - say 30mm - I would make a mess of my well thought pack dimensions because every seam would add overall 30mm extra fabric for each bond. That will end up in a much bigger pack than originally designed.

\illustrate[.75]{media/sketches/panel-back-seam-highlight.pdf}
{Be careful to always consider your dimensions with and without the extra seams}
{ske:panel-back-seam-highlight}

\begin{note}
  It's also the perfect allowance for binding the seams at a later stage with 20mm grosgrain ribbon.
\end{note}

\subsection{Side pockets and compression straps working together}\label{sec:construction-side-pockets}

\subsection{Bottom section cut}

\illustrate{media/sketches/pack-bottom-section-cut.pdf}
{Section cut of the bottom construction including reinforcements and padding}
{img:pack-bottom-section-cut}

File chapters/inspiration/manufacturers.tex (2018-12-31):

There are too many manufacturers of backpacks for me to keep looking at everyone one of them. But over time, and in the lightweight to ultra-lightweight community, there are a couple of well respected names I always look forward to dissecting and use for reference. Smaller names tend to innovate more, where better established brands have more diversity and complexity. Both are a fantastic source for inspiration.

Generally speaking, UL packs have a lot in common, so I don’t focus all my attention on ultralight gear maker, instead, I do all I can to find innovative ways of dialling down on pack weight without compromising comfort too much.

Here is a very short list of where I look for inspiration every once in a while:

\begin{description}

  \index{reddit}
  \item [Reddit] Oh yeah, that’s where you want to go to get in touch with the community of fantastic trekker/hikers who make packs. There are plenty of platform and communities out there, I personally roam these the most: \textit{r/ultralight} and \textit{r/myog}.

  \item [HMG] Hyperlight Mountain Gear is well respected business for a variety of ultralight gear, and I just love their pack designs. I unfortunately do not own one (yet) as I find them a little pricey. But who knows.

  \item [KS (Kinpu San)] ultralight gear is a fantastic one-man custom pack making business held by Laurent, out of Japan. I personally own his Tao pack, and I’ve had very comfy, very long days of hiking with it. This was the pack I brought with me to a short trek in Scotland, and the simple features held great in all weather with a light load (6-7kg).

  \item [Osprey] Over the years, Osprey has made a name for themselves by making very decently priced, sturdy and not too heavy packs. I’ve own an Exos for a few years, and still take it for a spin every once in a while. This was the pack I brought with me in the Himalayas, and I couldn’t have been happier with its performance with a medium load (9kg).

  \item [Sierra Design] A very interesting brand if only for the fact that they don’t do 100\% symmet- rical packs ! Think about how often you strap the same thing on the same side of the pack ? Well, maybe having a symmetrical design is not the best option. I certainly like the concept.

  \item [ÜLA] ÜLA is definitely a good place to look at. It’s a refreshing combination of ultralight - very simple - designs, with a more complex cut (not the usual rectangle pack) then most.

  \item [MLD] Mountain Laurel Design is also one of my personal favourite, although I never had a chance to try one out. They work from basic shapes, but have tons a very smart details that make it a great selection of packs.

  \item [ZPacks] Their packs are simple but effective. And they have a frame ! Which is quite rare for UL designs. I haven’t had a chance to wear one yet and see how it carries.

  \item [Decathlon] A big outdoor name from France who does more research on fabrics and designs than people might think. They do lack specialised equipment, but instead try to innovate a lot, so I always keep an eye on what they come up with. I’ve own many of their day packs, and have gotten my hand on many different trekking/hiking designs, and they all came up surprisingly close to what I consider lightweight.

\end{description}

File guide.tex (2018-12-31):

\documentclass[12pt]{report}
\usepackage[a4paper, margin=2cm]{geometry}
\usepackage[english]{babel}
\usepackage[figurename=Illustration]{caption}
\usepackage{tikz}
\usepackage{gensymb}
\usepackage{sidecap}
\usepackage{float}
\usepackage{hyperref}
\usepackage{makeidx}
\usepackage{titlepic}
\usepackage{mathtools}

\input{lib/colors}
\input{lib/environments}

\setlength{\parskip}{\baselineskip}
\setlength{\parindent}{0pt}
\makeindex

\title{
Rugged Frog's Polygon Pack
\newline
\textit{From Design to Construction}
}
\author{Arthur Van de Wiele}
\titlepic{}

\begin{document}
  \maketitle
  \tableofcontents

  \include{chapters}

  \cleardoublepage
  \phantomsection
  \addcontentsline{toc}{chapter}{\listfigurename}
  \listoffigures

  \cleardoublepage
  \phantomsection
  \addcontentsline{toc}{chapter}{\listtablename}
  \listoftables

  \cleardoublepage
  \phantomsection
  \addcontentsline{toc}{chapter}{\indexname}
  \printindex

\end{document}

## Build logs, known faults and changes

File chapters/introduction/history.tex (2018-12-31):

The outdoors always helped me balance my somewhat stressful and chaotic work life with some blessed moments of calm and quiet. Before taking on sewing, I had spent a lot of time hiking around the world, and although I don't consider myself an ultralight backpacker, I do make conscious decisions on what to pack on a trip based on weight and versatility. At the end of the day, it always came down to my gear not being one hundred percent suited to my backpacking style, to the gear I usually carried, or simply to the aesthetics I was attracted to. More often than not, I ended up with having to carry more than necessary, or spent more money than I should have on more specialised gear.

Designing my own backpacks came quite naturally. I happened to already own a handful of them, each one with their pros and cons. I knew what I liked or disliked, what I used, and what I did not. I've always slightly modified my packs to remove unnecessary weight on them, just so I can focus on carrying the essential on a longer distance, or simply with less efforts. All that trimming brought up many questions - and answers - about the structure of today's backpack, their versatility, and - by design - their average target group.

From there on, the jump to making a complete pack was mostly about acquiring the skills, researching the fabrics and components, and gathering tons of drawings in the process. It is from those drawings that I started putting together my first packs. Suffice to say, my initial attempts barely qualified as functional, but they did serve a purpose. I used the flaws of each pack to enhance the next design, and the next, and so on. I also started paying more attention to all the packs I could get my eyes and hands on. I spent time analysing those designs and foraging through other manufacturer's collections just so I could build up some kind of a knowledge base on how other people solved the same problems I was facing (or was about to face). To complete my training, I got my hands on a sewing machine and started practicing as often as I could, sewing together pouches, stuff sacks, and small yet more complicated items using, for example, velcro or zippers. The idea was to slowly ramp up towards putting packs together, which was my goal from the start. The next logical step was to use different - more specialised - fabrics, and experiment with less ordinary components, until I finally built up the confidence to work on more complex pack designs. I will present one of my most recent packs throughout this document to illustrate my words with a real life example.

You will have noticed it by now, I am the kind of person who can spend hours thinking about how to do something before ever getting hands-on. Now, designing a backpack has a lot to do with planning ahead, but - as I learnt since - there is no amount of planning which can compensate for the lack of getting your hands dirty. Anyone willing to embark on this adventure should consider balancing equally designing and planning time with time for experimenting and building mock-ups. There is - in the end - no time better spent on than putting together an inexpensive and simplified mock-up only for the purpose dissecting it thoroughly. Keep this in mind before spending money on more expensive fabrics and potentially making a mess of it. On the plus side, if one of these mock-ups turns out alright, you can always offer it to friends and family.

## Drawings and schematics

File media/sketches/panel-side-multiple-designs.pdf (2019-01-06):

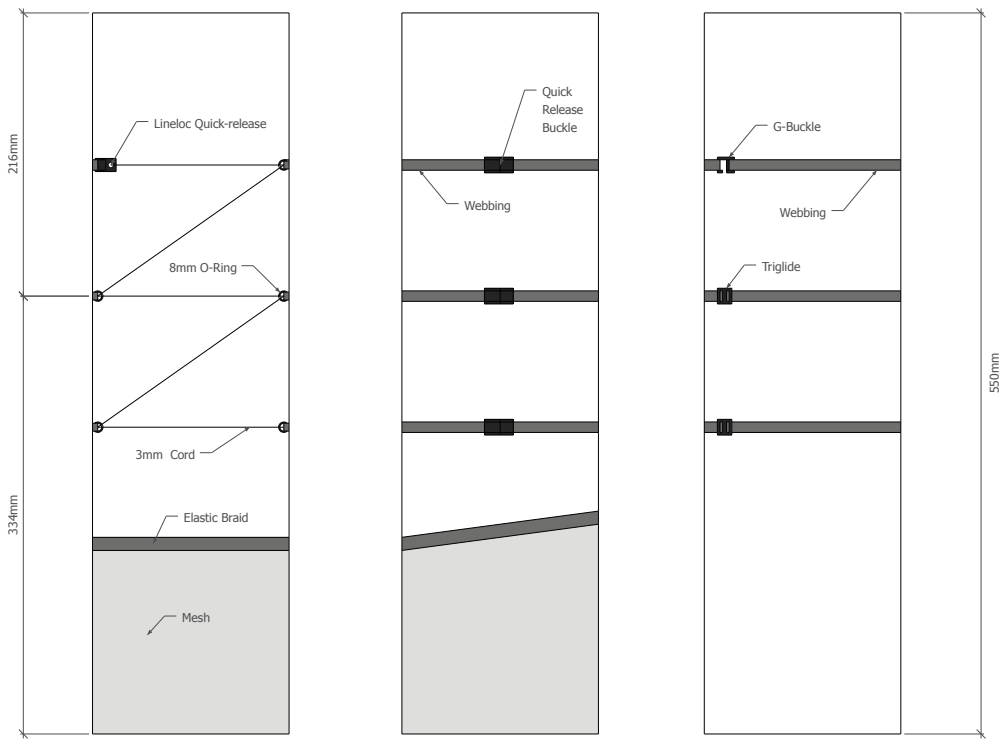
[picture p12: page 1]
8mm O-Ring; Mesh; Elastic Braid; Quick Release Buckle; Triglide; G-Buckle; 3mm Cord; Webbing

Lineloc Quick-release

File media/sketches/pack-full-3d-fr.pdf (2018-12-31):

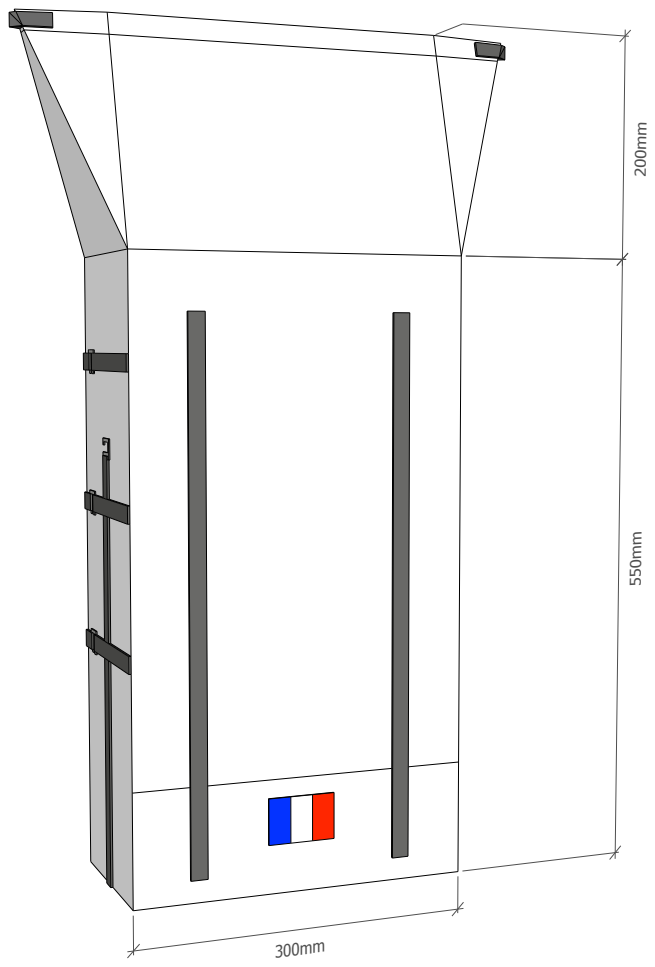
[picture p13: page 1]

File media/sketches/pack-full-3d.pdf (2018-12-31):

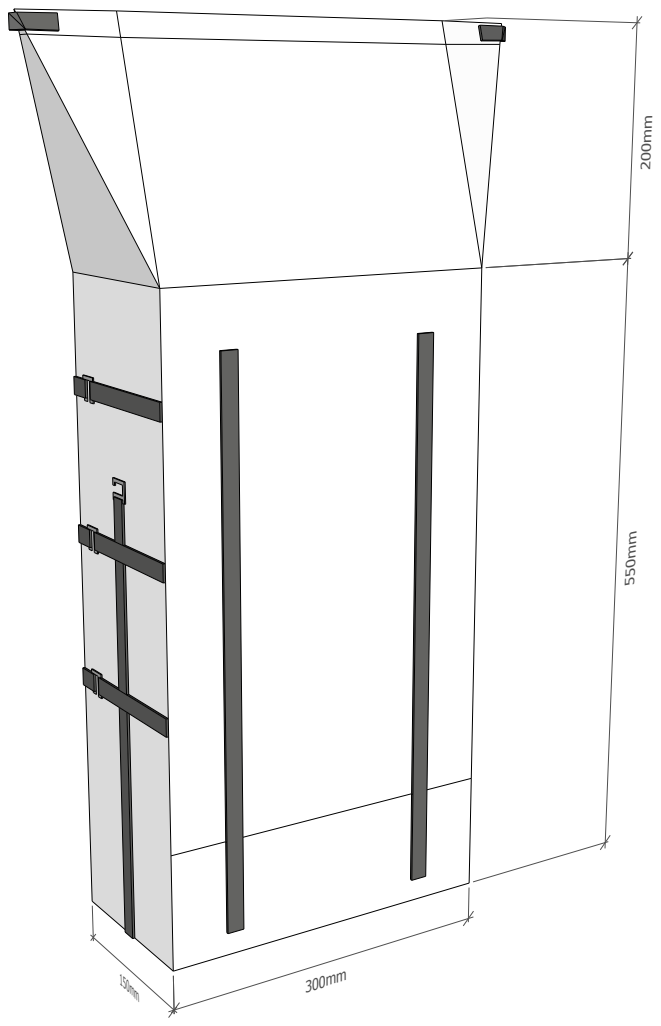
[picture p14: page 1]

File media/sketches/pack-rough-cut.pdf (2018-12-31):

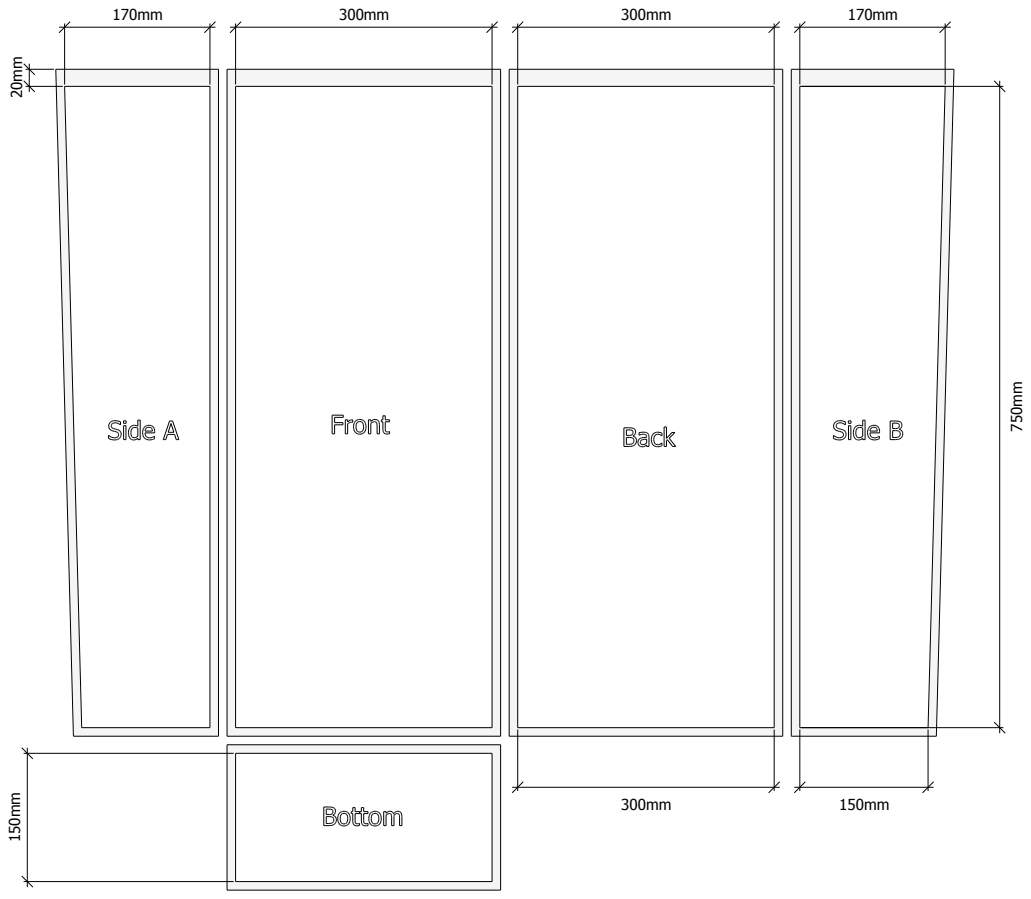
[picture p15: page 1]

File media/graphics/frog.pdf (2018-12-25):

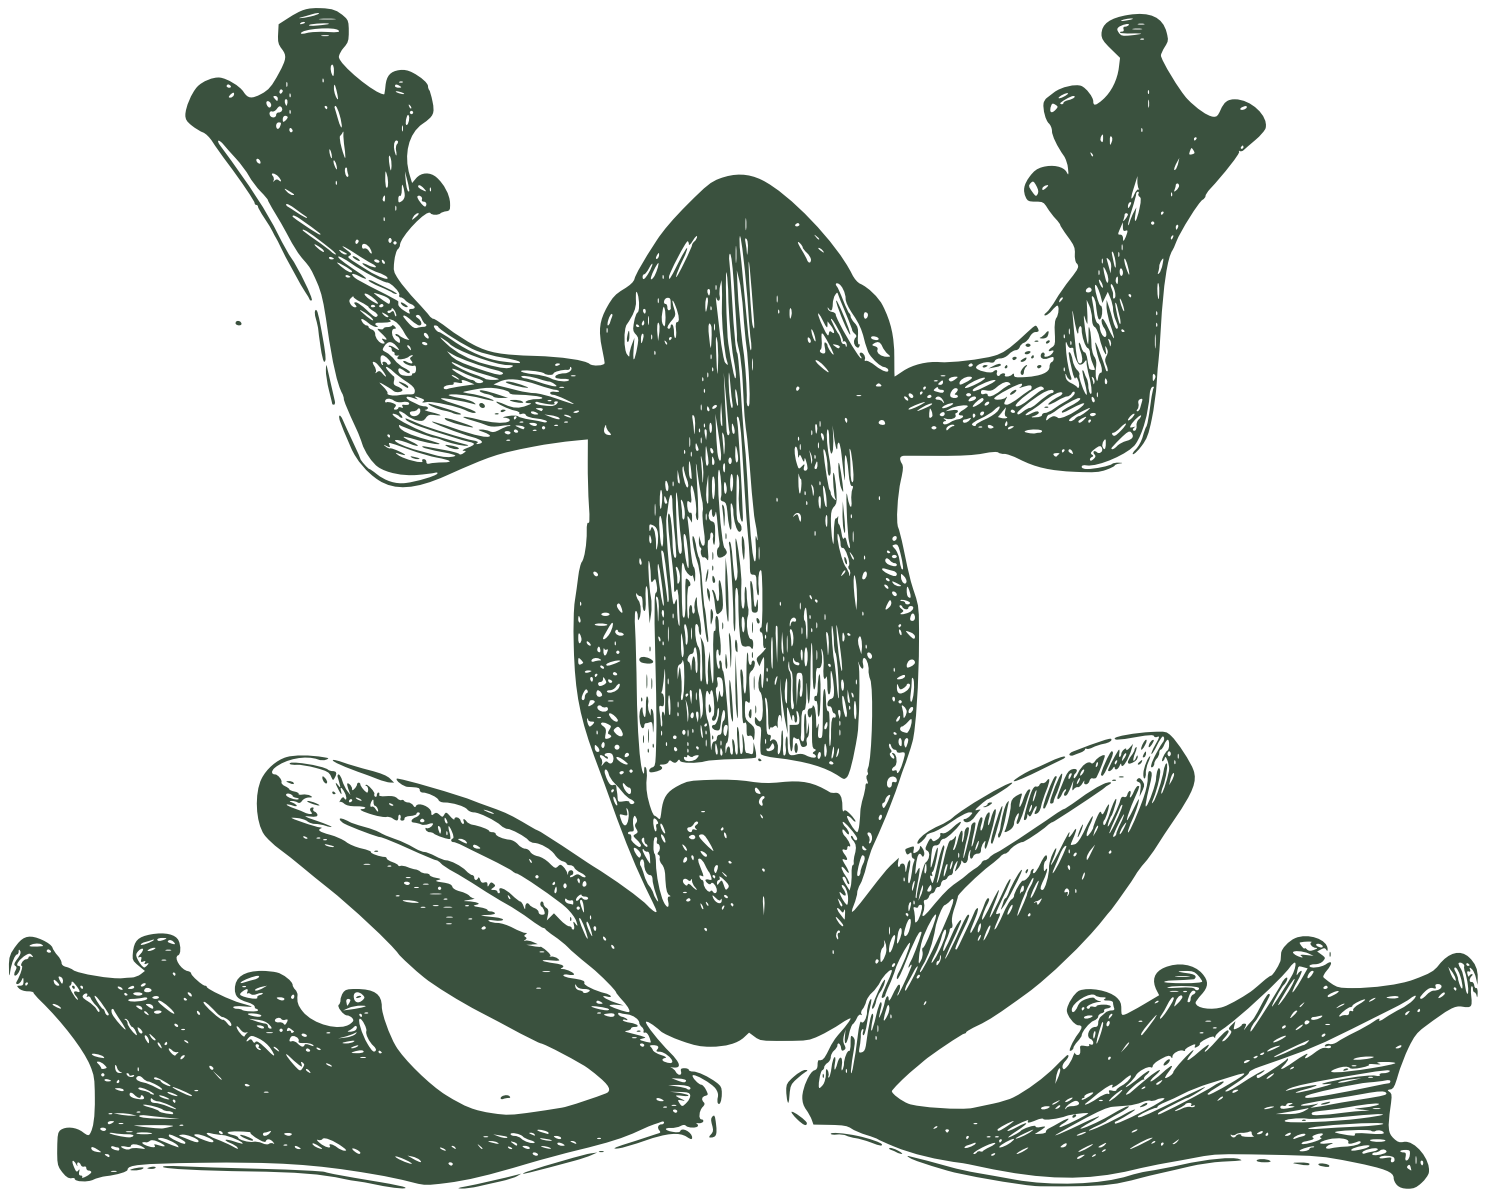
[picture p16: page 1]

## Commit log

2018-11-03 fix(workspace) Adding missing closing curly bracket.
2018-11-03 refactor(inspiration/learning) Add label to the gear-database snapshot.
2018-11-03 feat(material) Add draft of the fabrics and materials chapter with documentation of Cordura.
2018-11-03 fix(materials/samples) Fix typo in reference to image.
2018-11-03 fix(materials/samples) Fix typo in introduction.
2018-11-03 feat(materials/fabrics) Add soaking resistance to selection criteria.
2018-11-04 feat(material/fabrics) Add placeholder and sample image for mesh and nets.
2018-11-04 feat(material/fabrics) Add placeholder and sample photos for 3d mesh fabrics.
2018-11-04 feat(material/fabrics) Add placeholder and first photos of synthetic coated fabrics.
2018-11-04 feat(material/components) Add placeholder and first pictures of useful components.
2018-11-04 feat(material) Add new fabrics placeholders to the material index.
2018-11-04 feat(pack) Add chapter about the pack and loads of photos documenting the construction of the pack, straps, hip belt, extra volume strap.
2018-11-10 fix(chapters/design,chapters/materials) Fix mismatched references.
2018-12-29 feat(techniques/stitching) Add paragraph on using high quality thread.
2018-12-29 proof(techniques/stitching) Proofread the section on using high quality thread.
2018-12-29 feat(design/dimensions) Add draft of dimensions and measurment section including illustration.
    [pack-rough-cut.skp]
2018-12-30 feat(media/sketches) Clean up rought cut sketch and add front 2D design.
    [pack-front.skp, pack-rough-cut.skp]
2018-12-31 refactor(materials) Use new illustrate function.
2018-12-31 refactor(materials+pack) Use new vertillustrate function.
2018-12-31 feat(materials) Add section placeholder for ccf padding.
2018-12-31 feat(sketches) Add bottom section cut detailed 2D illustration.
    [pack-bottom-section-cut.skp]
2018-12-31 feat(design/construction) Add placeholder and illustration for construction documentation.
    [pack-bottom-section-cut.skp]
2018-12-31 fix(sketch) Fix velcro seam allowance in rought cut render.
    [pack-rough-cut.skp]
2018-12-31 fix(sketch) Fix velcro seam allowance in pack front render and rename.
    [pack-front.skp, panel-front-design.skp]
2018-12-31 feat(sketches) Add back panel design and hints drawings and update bottom cut.
    [pack-bottom-section-cut.skp, panel-back-design.skp, panel-back-seam-highlight.skp]
2018-12-31 feat(design/dimension) Add disclaimer subsection on hidden seams and impacts on cut-outs.
2018-12-31 fix(sketches) Fix missing gear loop on front panel design.
    [panel-front-design.skp]
2018-12-31 feat(design/dimensions) Add 3D crude render of the pack.
    [pack-full-3d.skp]
2018-12-31 refactor(sketches) Make all quotations and callouts black and white.
    [pack-rough-cut.skp, panel-front-design.skp]
2018-12-31 feat(sketches) Finishing up crude 3D render.
    [pack-full-3d.skp]
2018-12-31 feat(titelpage) Add french flag to the 3d render for the title page only.
    [pack-full-3d.skp]
2019-01-02 feat(design/dimensions) Add illustration for side panel.
    [panel-side-design.skp]
2019-01-03 refactor(techniques) Extract sewing thread to its own section.
2019-01-06 feat(sketches) Add example of different side panel designs.
    [panel-side-multiple-designs.skp]
